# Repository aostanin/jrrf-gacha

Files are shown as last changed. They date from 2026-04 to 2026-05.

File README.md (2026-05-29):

# ⚡ Lightning Gacha

A 3D-printed gacha (capsule toy) machine that dispenses a capsule when you
pay over the Bitcoin Lightning Network. Built for **Japan RepRap Festival
2026**.

```
Bitcoin Wallet → LNbits → Raspberry Pi → Stepper Motor → Capsule
```

Scan a QR, send a Lightning payment, the Raspberry Pi sees it arrive
over a WebSocket from LNbits, and steps a NEMA-17 motor to release one
capsule.

## Repository layout

| Path | What's in it |
| --- | --- |
| `model/` | 3D models (OpenSCAD sources, generated STL/3MF assets). |
| `handout/`  | One-page A4 handout in English and Japanese (Typst → PDF). |
| `software/` | Raspberry Pi software: LNbits WebSocket monitor + motor driver.  |
| `flake.nix` | Root Nix flake providing the dev shell for building the handout. |

## Building the handout

```sh
nix develop          # one-time: enter the dev shell with typst + tools
handout/build.sh     # regenerates assets and compiles both PDFs in place
```

If you have [direnv](https://direnv.net/) installed, `direnv allow` once
and the shell auto-activates on `cd`.

## Running on the Raspberry Pi

The `software/` directory holds the runtime that listens for Lightning
payments and drives the stepper motor:

- `lnbits-monitor.py` — opens a WebSocket to LNbits and watches for
  matching payments.
- `motor.py` — steps a NEMA-17 motor (55° forward, pause, 55° back) over
  GPIO when a payment lands. Pin assignments (`STEP_PIN=17`, `DIR_PIN=27`,
  `EN_PIN=22`) are at the top of the file.

Install the Python dependencies on the Pi:

```sh
pip install websockets rpi-gpio
```

Wire the TMC2209 stepper driver to the GPIO pins above, then point the
monitor at your LNbits server and Lightning Address:

```sh
export LNBITS_URL=https://your-lnbits-server
export LNBITS_API_KEY=your-invoice-read-key
export LNBITS_LN_ADDRESS=your-address@example.com
export LNBITS_MIN_SATS=500
python lnbits-monitor.py
```

The monitor watches for payments to `LNBITS_LN_ADDRESS` of at least
`LNBITS_MIN_SATS` and runs `motor.py` once per matching payment.

## License

The code, OpenSCAD models, Typst sources, and other original work in this
repository are licensed under the [MIT License](LICENSE).

Third-party assets bundled in the repository keep their own licenses:

| Asset | License | Source / attribution |
| --- | --- | --- |
| `handout/_assets/icons/*.svg` (most) | ISC | [Lucide](https://lucide.dev/) — license note inline in each SVG. |
| `handout/_assets/icons/raspberry-pi.svg` | Trademark | [Raspberry Pi Ltd.](https://www.raspberrypi.com/trademark-rules/) Used descriptively to identify the Raspberry Pi hardware. |
| `model/sign/mdi/*.svg` | Apache 2.0 | [Material Design Icons](https://pictogrammers.com/library/mdi/) by Pictogrammers. See `model/sign/mdi/README.md`. |
| `model/opengrid/*.3mf` | CC BY 4.0 | [OpenGrid wall/desk framework](https://www.printables.com/model/1214361-opengrid-walldesk-mounting-framework-and-ecosystem) by David D. See `model/opengrid/README.md`. |
| `model/lid/Bitcoin_lightning_bolt.svg` | Public domain (community) | Lightning Network bolt symbol. |

The handout build also pulls Typst packages
([fletcher](https://typst.app/universe/package/fletcher),
[cetz](https://typst.app/universe/package/cetz),
[oxifmt](https://typst.app/universe/package/oxifmt)) and the
fonts Source Han Sans (SIL OFL), Roboto (Apache 2.0), and Hack Nerd Font
(MIT) — each under their respective upstream licenses.

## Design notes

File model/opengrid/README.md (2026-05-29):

# OpenGrid

Files in this directory are part of the **OpenGrid** wall/desk mounting
ecosystem and are **not covered by the repository's MIT license** — they keep
their original license.

- **Author:** David D
- **Source:** <https://www.printables.com/model/1214361-opengrid-walldesk-mounting-framework-and-ecosystem>
- **License:** [Creative Commons Attribution 4.0 International (CC BY 4.0)](https://creativecommons.org/licenses/by/4.0/)

You are free to share and adapt these files, including commercially, provided
you give appropriate credit to the original author.

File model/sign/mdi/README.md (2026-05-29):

# Material Design Icons

SVG icons in this directory are from the **Material Design Icons** library by
Pictogrammers and are **not covered by the repository's MIT license** — they
keep their original license.

- **Library:** Material Design Icons (community)
- **Maintainers:** Pictogrammers (Austin Andrews et al.)
- **Source:** <https://pictogrammers.com/library/mdi/>
- **License:** [Apache License 2.0](https://www.apache.org/licenses/LICENSE-2.0)

Apache 2.0 permits use, modification, and redistribution (including
commercially) provided attribution is preserved.

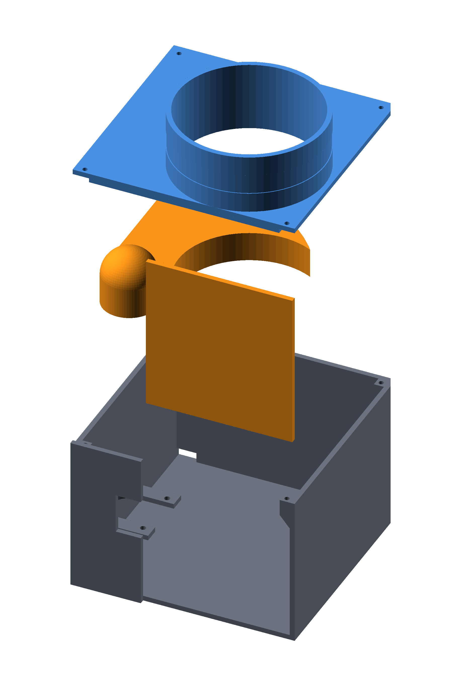
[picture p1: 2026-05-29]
handout/_assets/exploded.png

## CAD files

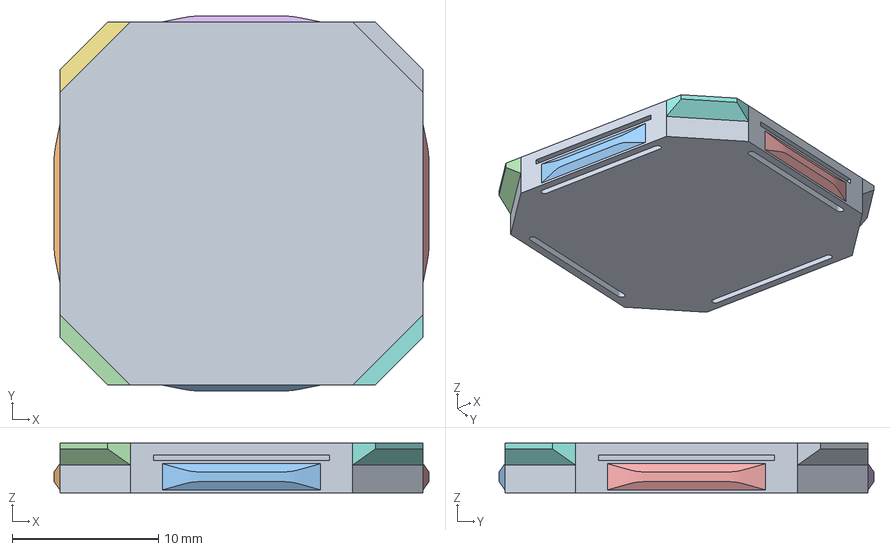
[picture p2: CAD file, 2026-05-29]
model/opengrid/opengrid-bare-lite-snap.3mf
25.6 x 25.6 x 3.40 mm
Inner

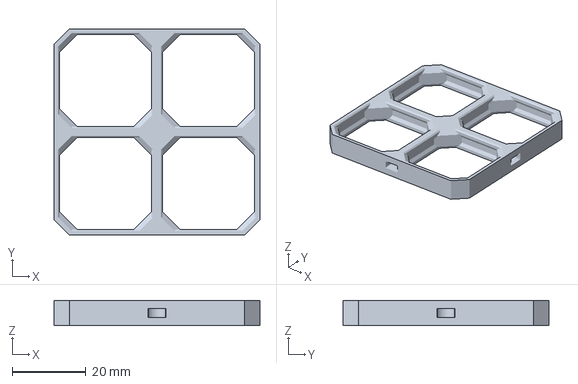
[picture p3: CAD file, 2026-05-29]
model/opengrid/opengrid-2x2.3mf
56.0 x 56.0 x 6.80 mm

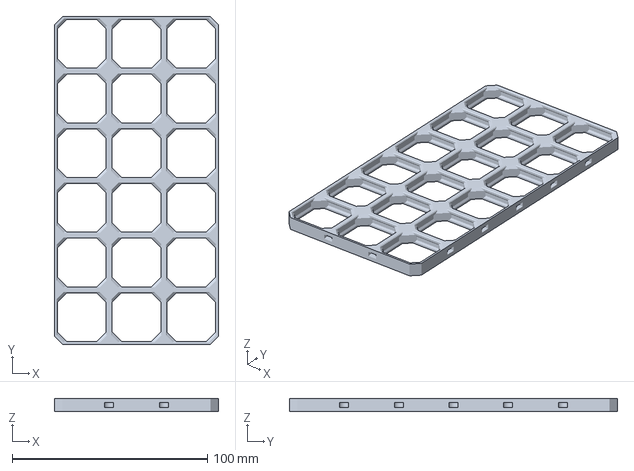
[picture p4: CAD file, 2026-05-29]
model/opengrid/opengrid-6x3.3mf
84.0 x 168.0 x 6.80 mm

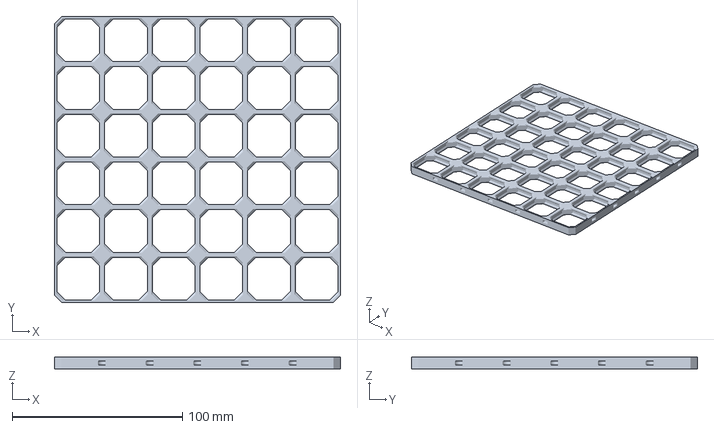
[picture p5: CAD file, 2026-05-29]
model/opengrid/opengrid-6x6.3mf
168.0 x 168.0 x 6.80 mm

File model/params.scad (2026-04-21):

m3_hole_d = 3.5;

wall_t = 3;

capsule_d = 75;
capsule_clearance = 10;
capsule_hole_d = capsule_d + capsule_clearance;

hose_id = capsule_hole_d + 2 * wall_t;
hose_clamp_h = 12;

motor_body = 42.3;
motor_body_h = 37.8;
motor_body_hole_d = 24;
motor_mount_spacing = 31;
motor_mount_hole_d = m3_hole_d;
motor_mount_hole_top_d = 6.5;
shaft_d = 5.4;
shaft_flat = 4.8;
shaft_l = 18;

plate_h = wall_t + motor_body_h + 5.4;

_size_side = 2 * wall_t + motor_body + capsule_hole_d;
_size_height = 3 * wall_t + capsule_hole_d;
size = [_size_side, _size_side, _size_height];
usb_cutout_size = [12, 6];

$fn = 72;

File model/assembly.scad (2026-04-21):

include <params.scad>
use <top.scad>
use <middle.scad>
use <bottom.scad>

top();
middle();
bottom();

translate([size.x - 2 * wall_t - capsule_hole_d / 2, 2 * wall_t + capsule_hole_d / 2, wall_t + capsule_d / 2])
  sphere(d=capsule_d);

// translate([size.x - 2 * wall_t - capsule_hole_d / 2, -5, wall_t + capsule_d / 2])
// sphere(d=capsule_d);

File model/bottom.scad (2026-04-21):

include <params.scad>

module lid_hole() {
  s = 6;
  screw_h = 10;
  screw_d = 3;
  start_h = size.z - 2 * screw_h;
  h = size.z - wall_t;

  difference() {
    translate([0, 0, h - screw_h])
      linear_extrude(screw_h)
        square(s, s);

    translate([s / 2, s / 2, h - screw_h])
      linear_extrude(screw_h)
        circle(d=screw_d);
  }

  translate([0, 0, start_h])
    linear_extrude(h - screw_h - start_h, scale=s / 0.1)
      square([0.1, 0.1]);
}

module bottom() {
  // Case
  difference() {
    cube([size.x, size.y, size.z]);
    translate([wall_t, wall_t, wall_t])
      cube([size.x - 2 * wall_t, size.y - 2 * wall_t, size.z - 2 * wall_t]);
    translate([0, wall_t, size.z - wall_t])
      cube([size.x, size.y - wall_t, wall_t]);
    translate([size.x - capsule_hole_d - 2 * wall_t, 0, size.z - wall_t])
      cube([capsule_hole_d + 2 * wall_t, wall_t, wall_t]);

    translate([size.x - capsule_hole_d - 2 * wall_t, 0, 0])
      cube([capsule_hole_d + wall_t + wall_t, wall_t, size.z - wall_t]);
    translate([size.x - capsule_hole_d - 2 * wall_t - 15, 0, plate_h - wall_t])
      cube([15, wall_t, shaft_l + 2 * wall_t]);

    translate([wall_t, size.y - wall_t, wall_t])
      cube([usb_cutout_size.x, wall_t, usb_cutout_size.y]);
  }

  // Motor mount
  translate([wall_t, wall_t, wall_t + motor_body_h]) {
    linear_extrude(wall_t)
      difference() {
        square(motor_body);

        translate([motor_body / 2, motor_body / 2]) {
          // Center cutout
          circle(d=motor_body_hole_d);
          translate([0, -motor_body_hole_d / 2])
            square([motor_body / 2, motor_body_hole_d]);

          // Mounting holes
          for (x = [-motor_mount_spacing / 2, motor_mount_spacing / 2]) {
            for (y = [-motor_mount_spacing / 2, motor_mount_spacing / 2]) {
              translate([x, y]) circle(d=motor_mount_hole_d);
            }
          }
        }
      }

    // Security
    translate([0, 0, wall_t]) {
      difference() {
        linear_extrude((motor_body - motor_body_hole_d) / 2, scale=[0, 1])
          square([(motor_body - motor_body_hole_d) / 2, motor_body]);
        translate([motor_body / 2, motor_body / 2, 0])
          linear_extrude((motor_body - motor_body_hole_d) / 2) {
            for (y = [-motor_mount_spacing / 2, motor_mount_spacing / 2]) {
              translate([-motor_mount_spacing / 2, y]) circle(d=motor_mount_hole_top_d);
            }
          }
      }
    }
  }

  // Top holes
  translate([wall_t, wall_t, 0])
    lid_hole();
  translate([size.x - wall_t, wall_t, 0])
    rotate([0, 0, 90])
      lid_hole();
  translate([wall_t, size.y - wall_t, 0])
    rotate([0, 0, -90])
      lid_hole();
  translate([size.x - wall_t, size.y - wall_t, 0])
    rotate([0, 0, 180])
      lid_hole();
}

bottom();

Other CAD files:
model/exploded.scad
model/lid/lid.scad
model/middle.scad
model/sign/qr.scad
model/sign/tiles.scad
model/top.scad

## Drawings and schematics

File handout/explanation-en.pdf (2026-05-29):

# LIGHTNING GACHA

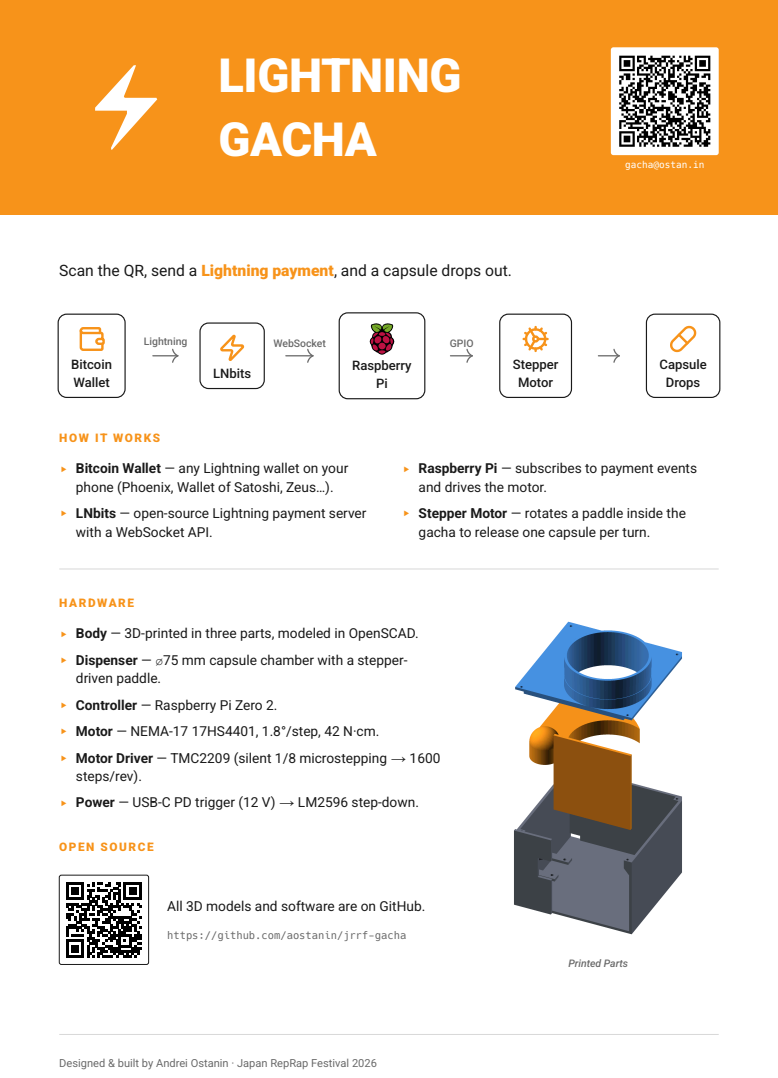
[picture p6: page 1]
Lightning; WebSocket; GPIO; Bitcoin; Wallet; LNbits; Raspberry; Stepper Motor; Capsule Drops; Printed Parts

gacha@ostan.in

Scan the QR, send a Lightning payment, and a capsule drops out.

▸ Bitcoin Wallet — any Lightning wallet on your
phone (Phoenix, Wallet of Satoshi, Zeus…).
▸ LNbits — open-source Lightning payment server
with a WebSocket API.

▸ Raspberry Pi — subscribes to payment events
and drives the motor.
▸ Stepper Motor — rotates a paddle inside the
gacha to release one capsule per turn.

▸ Body — 3D-printed in three parts, modeled in OpenSCAD.
▸ Dispenser — ⌀75 mm capsule chamber with a stepper-
driven paddle.
▸ Controller — Raspberry Pi Zero 2.
▸ Motor — NEMA-17 17HS4401, 1.8°/step, 42 N·cm.
▸ Motor Driver — TMC2209 (silent 1/8 microstepping → 1600
steps/rev).
▸ Power — USB-C PD trigger (12 V) → LM2596 step-down.

All 3D models and software are on GitHub.

https://github.com/aostanin/jrrf-gacha

Designed & built by Andrei Ostanin · Japan RepRap Festival 2026

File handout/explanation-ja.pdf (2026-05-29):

# ライトニング

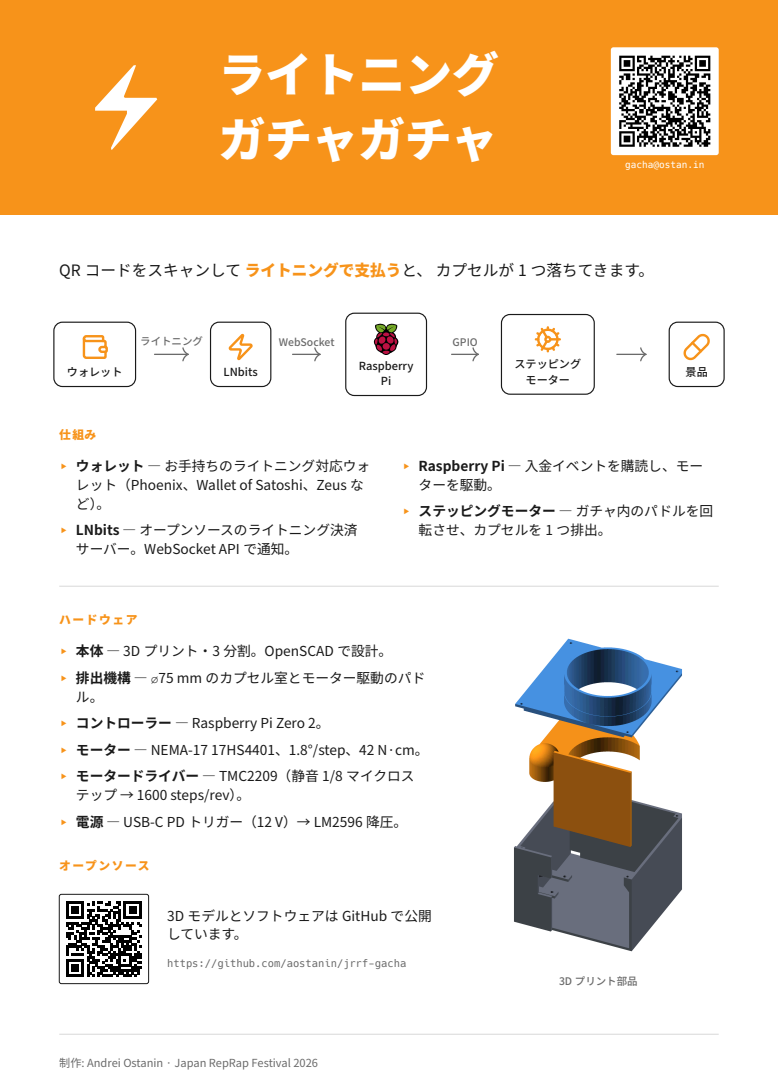
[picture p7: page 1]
ガチャガチャ; gacha@ostan.in; ライトニング; WebSocket; GPIO; ウォレット; LNbits; Raspberry; ステッピング; モーター; 仕組み; ハードウェア; オープンソース; 3D プリント部品

QR コードをスキャンして ライトニングで支払うと、 カプセルが 1 つ落ちてきます。

▸ ウォレット — お手持ちのライトニング対応ウォ
レット（Phoenix、Wallet of Satoshi、Zeus な

▸ Raspberry Pi — 入金イベントを購読し、モー
ターを駆動。

▸ ステッピングモーター — ガチャ内のパドルを回
転させ、カプセルを 1 つ排出。

▸ LNbits — オープンソースのライトニング決済
サーバー。WebSocket API で通知。

▸ 本体 — 3D プリント・3 分割。OpenSCAD で設計。

▸ 排出機構 — ⌀75 mm のカプセル室とモーター駆動のパド

▸ コントローラー — Raspberry Pi Zero 2。

▸ モーター — NEMA-17 17HS4401、1.8°/step、42 N·cm。

▸ モータードライバー — TMC2209（静音 1/8 マイクロス
テップ → 1600 steps/rev）。

▸ 電源 — USB-C PD トリガー（12 V）→ LM2596 降圧。

3D モデルとソフトウェアは GitHub で公開
しています。

https://github.com/aostanin/jrrf-gacha

制作: Andrei Ostanin · Japan RepRap Festival 2026

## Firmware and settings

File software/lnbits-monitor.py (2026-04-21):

#!/usr/bin/env python3

import asyncio
import json
import os
import subprocess
import sys
import websockets

SCRIPT_DIR = os.path.dirname(os.path.abspath(__file__))


async def monitor(base_url: str, api_key: str, min_sats: int, ln_address: str):
    ws_url = f"{base_url}/api/v1/ws/{api_key}"
    print(f"Connecting to {ws_url}")
    print(f"Filtering: ln_address={ln_address}, min_sats={min_sats}")

    while True:
        try:
            async with websockets.connect(ws_url) as ws:
                print("Connected, waiting for payments...")
                async for message in ws:
                    data = json.loads(message)
                    payment = data.get("payment", {})
                    extra = payment.get("extra", {})
                    amount_sats = payment.get("amount", 0) // 1000

                    addr = extra.get("lnaddress", "")
                    memo = payment.get("memo", "")
                    print(f"Payment received: {memo} - {amount_sats} sats (address: {addr})")

                    if ln_address and addr != ln_address:
                        print(f"  Skipped: address mismatch (want {ln_address})")
                        continue
                    if amount_sats < min_sats:
                        print(f"  Skipped: {amount_sats} sats < {min_sats} min")
                        continue

                    print("  Running motor...")
                    try:
                        subprocess.run([sys.executable, os.path.join(SCRIPT_DIR, "motor.py")], check=True)
                        print("  Motor run complete")
                    except subprocess.CalledProcessError as e:
                        print(f"  Motor script failed: {e}", file=sys.stderr)
        except websockets.ConnectionClosed:
            print("Connection closed, reconnecting in 5s...")
            await asyncio.sleep(5)
        except Exception as e:
            print(f"Error: {e}, reconnecting in 5s...", file=sys.stderr)
            await asyncio.sleep(5)


def main():
    base_url = os.environ.get("LNBITS_URL", "").rstrip("/")
    api_key = os.environ.get("LNBITS_API_KEY", "")
    min_sats = int(os.environ.get("LNBITS_MIN_SATS", "0"))
    ln_address = os.environ.get("LNBITS_LN_ADDRESS", "")

    if not base_url or not api_key:
        print("Set LNBITS_URL and LNBITS_API_KEY environment variables", file=sys.stderr)
        sys.exit(1)

    base_url = base_url.replace("https://", "wss://").replace("http://", "ws://")
    asyncio.run(monitor(base_url, api_key, min_sats, ln_address))


if __name__ == "__main__":
    main()

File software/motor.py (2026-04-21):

import RPi.GPIO as GPIO
import time

STEP_PIN = 17
DIR_PIN = 27
EN_PIN = 22

ANGLE_DEG = 55
PAUSE_SEC = 1
STEPS_PER_REV = 1600
STEP_DELAY = 0.001

STEPS = int(STEPS_PER_REV * ANGLE_DEG / 360)

def rotate(steps, direction):
    GPIO.output(DIR_PIN, direction)
    for _ in range(steps):
        GPIO.output(STEP_PIN, GPIO.HIGH)
        time.sleep(STEP_DELAY)
        GPIO.output(STEP_PIN, GPIO.LOW)
        time.sleep(STEP_DELAY)

try:
    GPIO.setmode(GPIO.BCM)
    GPIO.setup(STEP_PIN, GPIO.OUT)
    GPIO.setup(DIR_PIN, GPIO.OUT)
    GPIO.setup(EN_PIN, GPIO.OUT)

    GPIO.output(EN_PIN, GPIO.LOW)  # enable driver

    rotate(STEPS, GPIO.HIGH)      # forward
    time.sleep(PAUSE_SEC)
    rotate(STEPS, GPIO.LOW)       # reverse

finally:
    GPIO.cleanup()
